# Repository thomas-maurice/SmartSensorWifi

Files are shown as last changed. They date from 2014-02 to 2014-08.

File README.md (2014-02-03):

# Smart Sensor WiFi
## General information

 * Developpement status : *work in progress*
 * Project version   : 0.1 alpha

Project led by:

 * Thomas Maurice <Thomas.Maurice@polytech-lille.net>
 * Benoit Maliar  <Benoit.Maliar@polytech-lille.net>

## About the project
This project aims to build a network of sensors which can easily be
deployed into any building to monitor it. The sensors would be able to
monitor temperature, light, moist, presence and so on and send everything
to a centralized database into which data will be stored and processed.

We can easily imagine which use can be done of this kind of sensor networks
in the field of energy-efficient building.

For now, this project is part of a student project led by Polytech'Lille,
a french school of engineering.

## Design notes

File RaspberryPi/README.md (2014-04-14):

RaspberrySPI
============

A base class to implement full duplex SPI communication, simple to extand to create custom SPI drivers

A nice Doxygen powered doc can be found [here](http://doc.svartbergtroll.fr/raspberryspi).

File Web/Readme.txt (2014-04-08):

Manuel d'utilisation de la plateforme Web Smart Sensor Wifi

Index : Connexion
Ajout d'un capteur
Suppression d'un capteur
Recherche d'un capteur
Administration

------------------WARNING------------------------

Don't forget to configure the 'connexion.php' file with your configuration before using.

-----------------WARNING-------------------------

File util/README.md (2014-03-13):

# util

These files are provided as 'helpers' to use/dev/debug the project.
They are not quite documented/re-usable because their sole purpose
is being used in the Smart Sensor WiFi project's developement.
Of course everything here is under the GPL License.

## pyserialcom.py
This script provides a simple user-friendly and swaggy alternative to
*minicom*. It enables you to communicate with the mictocontroller via
the serial port. The advantage is that if a character is not printable,
it won't result in a horrible and unprintable result. You can choose
between an ASCII output, a hex output and a mixed output.

To launch it just type :

    ./pyserialcom.py [serialport] [baudrate=9600]

and enjoy ;)

## postJson.sh
This script is used to emulate the data send by a sensor to check
if the insersions into the database are effective or not.

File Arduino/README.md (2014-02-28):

# Smart Sensor WiFi - microcontroller Part
## General information

 * Developpement status : *work in progress*
 * Project version   : 0.1 alpha
 * Developper : Thomas Maurice <Thomas.Maurice@polytech-lille.net>

# Introduction
 
This project is a student project managed by Polytech Lille Engineering
School. It is led by two students, *Thomas Maurice* and *Benoit Maliar*. Both
students in 4th year.

The aim of the project is to create a distributed WiFi sensor network
that is able to regularly communicate various data to a central DB and
autoreconfigure itself in order to be energy efficient.

Note that the project is open source and you can modify it. Especially
the drivers for the RTC and the WiFi chip, you are more than welcome to
study and improve them.

# Hardware

The project uses the following hardware :

* An atmega328p (An Arduino Uno board for the developpement).
* A DS1302 real time clock for time-keeping.
* A photoresistor and temperature sensor.
* A WizFi210 WiFi chip.

# Getting the code's doc

This is easy. The documentation for the source code is located in the
code itself with **Doxygen** comments. This means that you have to install *doxygen*
on your computer and run `doxygen Doxyfile` in the Arduino folder. This will
generate a pretty HTML documentation in the `doxygen/html` folder. Feel free
to navigate it.

# Compiling

To compile the project you just need AVR-gcc installed. Just go in the
`Arduino` directory and run `make`. Everything will compile well. If
not, just undo your changes to my code !

It will create a nice .hex for upload. If your target is an Arduino board
then just type `make flash` to upload it using the built-in bootloader.
If it is just a bare-metal atmega328p then wire it up to your USBASP
device and run avrdude with the good options.

Have fun :)

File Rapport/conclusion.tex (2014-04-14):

\addcontentsline{toc}{section}{Conclusion}
	\section*{Conclusion}
		\par
		En conclusion, nous avons répondu à la problématique qui nous a été posée en fournissant un prototype de capteur qui envoie des données via le réseau Wifi. De plus, une plate-forme permettant de monitorer ces capteurs a été conçu.
		\par
		Un des points auquel nous n'avons pas totalement répondu est la sécurité du réseau. A la base, nous devions fournir un capteur capable d'envoyer ses données via le réseau de l'université (PEAP) mais cela n'a pas été possible avec le firmware fourni de base mais qui est possible en obtenant le firmware auprès du concepteur du shield Wifi. Néanmoins, le prototype final est tout de même capable de fonctionner sous WPA2.
		\par
		La façon dont nous avons réalisé le projet permet de continuer et d'améliorer assez aisément le projet en vu d'une évolution ou d'une mise en production.

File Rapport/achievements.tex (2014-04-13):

% !TEX encoding = UTF-8 Unicode
\section{Cahier des charges}
	\par
	Le cahier des charges a été formulé comme il suit : L'objectif du
	projet consiste en la conception et la réalisation de capteurs autonomes
	communiquant en WiFi afin de pouvoir remonter réguliérement des informations
	sur l'état des salles de cours. Les capteurs seront par exemple des détecteurs de
	lumières, de pression, de qualité de l'air, ...
	\par
	La communication sera obligatoirement réalisée en WiFi sur le réseau
	de l'université en respectant les contraintes de sécurité (WPA2, ...).
	\par
	Deux options sont possibles :
	\begin{itemize}
    \item Refaire complètement une carte avec un microcontroleur et une
    puce wifi (comme par exemple les \href{https://www.spark.io/}{spark})
    \item Réaliser un shield pour raspberry pi contenant les différents capteurs. 
	\end{itemize}
	
\section{Présentation de la réalisation}
	\subsection{Présentation de la partie web}
		\par
		La partie Web du projet offre une interface de supervision et de monitoring des capteurs. En effet, nous avons pense qu'il ne suffisait pas de réussir à envoyer des données en Wifi par le biais des capteurs, il fallait aussi pouvoir récupérer et stocker ces informations en vue d'un potentiel traitement. 
		\par
		On a donc décidé de récupérer ces informations dans une base de données qui serait gérée par une plateforme Web.
		\subsubsection{La base de données}
		\par
		La base de données que nous avons utilisée est celle offerte par Polytech'Lille, comme à chaque étudiant de l'école. Nous avons donc opté pour une base MySQL avec le panneau d'administration PHPMyAdmin. Le choix de MySQL est simplement justifié par une meilleure connaissance et habitude des requêtes et commandes SQL, contrairement à PosgreSQL (bien qu'il y ait peu de différences).
		\subsubsection{La plateforme Web}
		\par
		L'accès à la plateforme se fait via l'url suivante : \href{http://smartsensorwifi.plil.net}{Smart Sensor Wifi.}
		\\%
		Le site n'est pas en mode sécurisé (https) pour une raison simple : le shield Wifi ne supporte pas l'https dans le firmware actuel (celui livré de base). C'est donc pour cela que nous avons choisi de le mettre en http simple (bien qu'il puisse être basculé en https très rapidement et simplement sans poser aucun souci de compatibilité).
		\par
		Au niveau langage de programmation, le site est en HTML et PHP. Nous avons choisi le PHP, plutôt que le Python ou autre, car le PHP était plus familier et offrait toutes les opérations nécessaires. De plus, une petite partie du site utilise du Javascript afin de rendre plus dynamique et interactif le site.
		\par
		Au niveau design, nous avons décidé d'utiliser deux frameworks libres : Ink et Chart.js. Le premier gère le design global du site et le second est utile à la création de graphiques. Nous avons décidé d'utiliser des framework afin de rendre le site plus propre et d'offrir à l'utilisateur un outil visuellement agréable à utiliser.
		\par
		Au niveau technique, la plateforme est un simple intermédiaire entre, d'une part les capteurs et la base de données, et d'autre part, les utilisateurs et la base de données. D'un côté, le site récupère les informations que les capteurs lui envoie et stocke ces données dans la base. De l'autre côté,  à travers différents boutons et champs, l'utilisateur peut récupérer les informations qu'il désire.
		
	\subsection{Présentation de la partie capteur}
		\subsubsection{Le hardware}
		\par
		A la fin du projet, nous avons réalisé un prototype fonctionnel de ce
		que pourrait être le capteur. Il est important de noter que nous n'avons
		pas cherché à intégrer la solution mais plutôt à la développer en terme
		de fonctionnalités. De ce fait le prototype est assez volumineux mais
		sa taille peut aisément être réduite en utilisant des solutions à base
		de composants CMS notamment ce qui permettrait de réduire de manière
		significative l'encombrement de l'appareil.
		\par
		Le prototype final se compose donc de trois éléments principaux. Le coeur
		du système est réalisé avec un Arduino Uno. Une platine de développement
		sur microcontroleur basée sur un ATmega328P de chez Atmel. C'est dans cet
		Arduino qu'est flashé le programme du capteur. Vient en suite la partie
		qui prend en charge le WiFi, il s'agit d'un shield WiFi de chez GoTronic
		basé sur la puce WizFi210 de WizNet, cette dernière est interfacée avec
		l'Arduino via le port série. Enfin la dernière partie est un protoshield
		sur lequel est placé une breadboard sur laquelle sont enfichés les composants
		avec lesquels l'Arduino peut interagir, à savoir :
		\begin{itemize}
			\item Une photorésistante pour capter la luminosité
			\item Un capteur TMP36 de température
			\item Une RTC (Real Time Clock) DS1302
		\end{itemize}
		Notons que nous avons choisi ces capteurs pour leur facilité d'utilisation,
		mais dans l'absolu rien n'empêche d'utiliser n'importe quel autre capteur
		analogique ou TOR, ni même d'interfacer le système avec des choses plus
		complexes à base de SPI ou d'I$^2$C, étant donné que l'ATmega328P en a
		la possibilité.
		\par
		Le principe de fonctionnement du capteur est très simple. Une fois configuré
		à l'aide de \texttt{configurator} (dont le fonctionnement sera détaillé ci après)
		il vous suffit de déployer le capteur là où vous souhaitez qu'il opère et le
		laisser envoyer des mesures à intervalles d'une minute. On dispose ainsi
		d'un suivi efficace de l'environnement. Aussitôt que l'appareil est
		mis sous tension il va essayer de se connecter au réseau qui lui a été
		spécifié en configuration et une fois que cela s'est fait correctement il
		va passer en mode interruptif et enverra ses mises à jour toutes les minutes.
		Il faut aussi noter que pendant ce temps là, le capteur écoutera les connexions
		entrantes sur le port 80 et pourra ainsi être reconfiguré par ce biais à l'aide
		d'un set de commandes AT décris et documenté en annexe.
		
		\subsubsection{Le software}
		La partie logicielle du projet est découpée en deux parties. La première
		consiste en le firmware que nous avons chargé dans l'Arduino, et qui est chargé
		de gérer la carte WiFi et les différents capteurs.
		\par
		La seconde partie consiste en un logiciel de configuration écrit spécialement
		pour ce projet, il s'agit de \texttt{configurator}. C'est un script en python
		qui permet via une interface graphique plutôt intuitive de configurer un capteur,
		et ce que ça soit par le port série d'un capteur directement relié au PC en USB
		ou via le réseau en utilisant une socket TCP.

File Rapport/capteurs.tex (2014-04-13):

\section{Détail de la conception de la partie microcontrôleur du projet}
	\subsection{Le capteur}
		Lors de la réalisation du senseur il a fallu en premier lieu se fixer
		des objectifs à atteindre, afin d'être sûr d'aller dans une direction
		cohérente tout au long du projet. De  ce fait nous avons choisi d'opter pour
		la réalisation d'un prototype fonctionnel et relativement simple au début.
		Par relativement simple, nous entendions capable de lire un ou deux capteurs
		analogiques simples à mettre en place de manière à nous focaliser sur
		l'interfaçage du dispositif avec un serveur de données. Nous nous sommes
		donc d'avantage focalisés sur une approche plus logicielle du projet en
		écartant volontairement, par manque de temps, des considérations annexes
		comme la gestion de l'énergie ou la mise en place immédiate de capteurs
		très complexes. Le but était réellement de fournir une base saine sur laquelle
		il serait facile de s'appuyer à l'avenir.
		
		\subsubsection{La partie électronique}
		
		La partie électronique est la plus simple de l'appareil c'est donc celle
		là qui sera abordée en premier. Elle se compose simplement d'une photo résistance
		montée en pull up sur la patte analogique 1 de l'Arduino et d'un capteur de
		température câblé sur la patte analogique 2. Nous avons également câblé un bouton de
		mise à jour (dont l'utilité sera détaillée plus tard) sur la patte PD2
		ainsi que la real time clock sur trois pattes numériques de manière à pouvoir
		échanger des données. Tout ces composants ont été positionnés sur une breadboard
		de manière à ce que nous puissions facilement en modifier l'arrangement au fur et a mesure
		que nos besoins évoluaient dans le projet.
		\par
		Nous n'avons malheureusement pas eu le temps de réaliser de carte
		pour fixer ce design. Et il n'aurait pas été pertinent de le faire dans la mesure
		ou la conception, le routage et la fabrication d'une carte sont des activités pour
		le moins chronophages et qu'il a effectivement été plus productif pour nous de nous
		concentrer sur l'ajout de nouvelles fonctionalités au capteur. Cependant
		nous avons édités des PCB et des schémas électroniques disponibles en
		annexe qui permettent de réaliser une telle carte.
		
		\subsubsection{Conception du firmware de l'Arduino}
		La conception du firmware de l'arduino s'est découpée en plusieurs étapes.
		Pour commencer nous avons séparé les différentes fonctionnalités que nous
		souhaitions. D'un point de vue organisation cela s'est traduit par un fractionnement
		du code en plusieurs fichiers, chacun regroupant les fonctions relatives à un
		domaine, par exemple la gestion du port série, des CAN, de l'EEPROM et autre.
		\par
		Ensuite, une fois que la séparation logique des fonctionalités a été effectuée
		nous avons commencé à les développer une à une, en lançant à chaque fois une
		série de tests sur ce que nous avions créé, de manière à nous assurer que tout
		était bien conforme à ce que nous attendions. De cette manière nous pouvions
		réutiliser sans crainte le code que nous avions précédemment écrit puisqu'il
		avait été validé par une batterie de tests.
		\par
		Une attention toute particulière a été portée à la documentation. En effet si nous
		souhaitons que le projet puisse être repris les années suivantes il
		est indispensable de fournir une documentation valable, fiable et complète
		de manière à ce que n'importe qui ou presque soit en mesure de comprendre
		ce qui a déjà été réalisé de manière logicielle. Pour ce faire nous avont eu
		recours au système de documentation in-code Doxygen, qui grâce à un
		système de commentaires au formattage particulier permet de générer automatiquement
		une belle documentation HTML. Cette documentation navigable est facile à utiliser, avec outils
		de recherche intégré et liens entre les différentes fonctions documentées.
		Si vous souhaitez construire la documentation du programme rendez vous dans
		le répertoire Arduino et tapez simplement \texttt{doxygen} un dossier contenant
		le nécessaire sera généré pour vous !
		\par
		La seconde partie du projet, qui n'est au final même pas utilisée dans le prototype
		actuel, a été la réalisation d'un driver pour la real time clock de Maxim DS1302.
		Ce driver a été implémenté en utilisant le protocole de communication 3-Wire décrit dans
		la datasheet, c'est un protocole similaire au protocole SPI mais suffisamment différent de celui ci
		pour ne pas pouvoir utiliser le contrôleur SPI de l'Arduino. Le driver est fonctionnel et
		permet d'accéder aux registres de temps de la RTC ainsi qu'aux quelques octets de RAM qu'elle
		nous fourni en plus, ce qui peut être pratique si jamais l'arduino venait à en manquer. Toutes
		les informations nécessaires sont bien évidemment documentées dans le code et via Doxygen.
		\par
		Nous somme partis du constat que le fonctionnement du WiFi pouvait être parfois
		assez instable, et que de ce fait il serait appréciable que le capteur puisse se comporter
		comme une sorte de datalogger dans le cas où il serait dans l'incapacité momentanée de communiquer
		avec le serveur de donnée, que cela soit a cause du wifi ou d'un autre problème d'ailleurs.
		Pour cela nous avions pensé le coupler avec une flash (voir les schémas en annexe). Cela dit
		comme le composant n'était disponible qu'en format SOIC8 et que nous n'avons pas réalisé la carte
		il nous a été impossible de l'intégrer correctement. Une amélioration possible et très facile à
		mettre en oeuvre pour le projet serait donc l'intégration de cette flash et l'utilisation
		de la RTC pour soumettre en différé des données de mesures qui n'auraient pas pu être
		transmises à temps.
		\par
		La troisième partie du projet a été consacrée à faire en sorte que la configuration du capteur
		soit persistante entre les reboots. Durant les phases de développement nous ne nous étions pas
		vraiment occupés de cela mais dès que le programme est devenu plus compliqué il est devenu
		essentiel de stocker certains paramètres (d'identifications notamment) autrement qu'en dur
		dans le code. Il a donc fallu ajouter un module de gestion de l'EEPROM. La structure suivante a donc
		été choisie pour stocker des données :
		\begin{itemize}
			\item L'EEPROM est découpée en différents secteur de taille fixé à la compilation
			\item Chaque secteur contient un octet de taille et $N$ octets de données ($N < 255$)
			\item Chaque secteur est uniquement défini par sa position en mémoire
		\end{itemize}
		
		Cette solution présente l'avantage d'être très simple à mettre en place d'un point de vue
		logiciel, ce système souffre cependant d'un gros problème qui est que l'on ne peut
		pas connaître de manière dynamique la taille maximale des données que l'on peut ranger
		dans un segment. Ce qui implique que le programmeur fasse très attention aux données qu'il
		manipule, de manière à ne pas provoquer de débordement sur un autre segment. Ceci dit,
		ce problème n'est pas vraiment critique puisqu'une simple réécriture de la configuration
		rétablira tout correctement. Ceci fait également partie des améliorations possibles
		du projet.
		
		\par
		La quatrième partie du projet a sans aucun doute été la plus difficile à réaliser. En
		effet après s'être occupé des briques élémentaire qui compose le capteur (communiquer
		en série, lire des capteurs analogiques, lire la RTC). Il a fallu regrouper tout ça
		ensemble et l'envoyer sur internet. Pour se faire, il a d'abord fallu comprendre comment
		fonctionnait la carte WiFi. La datasheet n'étant pas toujours très claire, ni très complète
		il a d'abord fallu passer par une phase \og{} d'exploration \fg{} de la carte via le port
		série, de manière à comprendre précisément ce qu'elle attendait de nous en terme de commandes.
		La carte se configurait finalement par un set de commandes AT via le port série et malgré
		les quelques imprécisions de la datasheet nous avons finalement été capables de nous identifier
		sur un réseau spécialement créé pour l'occasion.
		
		\par
		A partir de là a été développé une petite bibliothèque qui intègre les fonctions réseau de base,
		à savoir s'identifier sur un réseau avec des paramètres donnés, soumettre des requêtes HTTP et
		vérifier le retour des commandes AT de manière à réitérer plusieurs fois une tentative de connexion
		qui aurait échoué. Cette bibliothèque fonctionne sur le port série via une scrutation, elle n'utilise
		pas d'interruptions pour avoir plus de contrôle et intercepter tout ce qui circule sur le port série
		et le conserver au sein du même contexte (il est préférable que le retour d'une commande reste interceptée
		par la fonction qui l'a émise plutôt que de devoir passer par une interruption globale et deviner
		quelle fonction a besoin des données reçues).
		
		\subsubsection{Communication avec l'application web}
		Une fois la carte configurée et connectée au réseau, il a fallu envoyer des données de mise à jour au
		site de Benoit. Nous avions au départ pensé à faire ça via post en JSON, simplement ça aurait
		été trop long et gourmand à mettre en place niveau mémoire (les données post doivent avoir
		une longueur définie et il faut encoder les caractères "{:," qui sont très utilisées dans une
		chaine JSON ce qui aurait rendu l'envoi des données affreuse). Du coup nous avons opté pour un
		format d'envoi en post classique. Voici par exemple la requête POST que le capteur "cap1" doté du mot de passe
		"coucoutuveuxvoirmadata" aurait envoyé :
		
		\begin{verbatim}
    POST /recup.php HTTP/1.0
    Host: smartsensorwifi.plil.net
    Content-type: application/x-www-form-urlencoded
    Content-length: 100
    
    temp=140&lum=17&mid=cap1&mpass=coucoutuveuxvoirmadata
		\end{verbatim}
		
		\par Notons que les valeurs envoyées peuvent paraître étranges, mais elle ne sont que la lecture
		directe du CAN de l'ATmega, la serveur les traitera pour les transformer en température ou
		déterminer le seuil de luminosité. Ainsi on décharge le microcontrôleur d'une partie
		du travail.
		
		\subsubsection{Reconfiguration du capteur}
		Une fois que le projet est capable de communiquer avec l'appli web, de soumettre
		des données, de se connecter à un réseau et ce genre de chose il ne lui manque pas beaucoup de fonctionnalités.
		Ceci dit une fonctionnalité indispensable s'est vite faite ressentir :
		le besoin de pouvoir reconfigurer le capteur à distance. En effet, le
		seul moyen de reconfigurer le capteur était en modifiant en dur dans le code les identifiants et
		de reflasher le programme ensuite, ce qui n'est pas pratique.

		Pour palier à ce problème nous avons donc créé un set relativement complet de commandes AT,
		documentées en annexe. L'idée est que le capteur écoute ce qu'il se passe sur son port série
		et dès qu'une commande AT est reconnue elle est exécutée pour peu que l'on soit authentifié sur
		le capteur. Pour se faire nous avons établi deux modes de configuration, une configuration "locale" via
		le port série, et une reconfiguration à distance via le réseau. 
		
		\subsubsection{Principales difficultés rencontrées}
		
	\subsection{Configurator.py}
	\begin{wrapfigure}{r}{40mm}
		  \centering
		  
		  \caption{Interface de configurator}
		  \vspace{-20mm}
	\end{wrapfigure}
		Afin que l'utilisateur n'ai pas a se munir de minicom ou de netcat pour reconfigurer
		ses capteurs, nous avons choisi de développer un logiciel dont le rôle est de se
		charger de la configuration à la place de l'utilisateur. Qu'il s'agisse d'une configuration
		locale via le port série ou à distance via le réseau, configurator fait le lien
		entre l'utilisateur et son capteur. Le logiciel dispose d'une interface très simple composée
		de quelques champs et de deux boutons, un pour rapatrier la configuration d'un capteur et l'autre
		pour envoyer une configuration à un capteur. De cette manière il n'est plus utile de connaître
		par coeur les commandes AT nécessaires à la configuration de l'appareil. Ce logiciel a été
		réalisé en python avec pygtk, glade2 et pyserial.
	
	\subsection{Tentative de substitution par une solution a base de RaspberryPi}
		Comme la carte WizFi tardait à arriver, nous avons pensé opter pour une solution alternative
		pour réaliser le capteur, à base d'une RaspberryPi. Certes la solution était un peu surdimensionnée
		pour ce que l'on voulait en faire, mais comme cela on aurait eu quelque chose de fonctionnel
		à montrer lors de la soutenance. L'idée était d'utiliser les GPIO de la Raspberry pour
		l'interfacer avec le monde exterieur.
		\par
		Malheureusement la RaspberryPi est un appareil qui ne dispose pas d'entrées analogiques,
		ce qui est assez peu pratique pour lire une température ou une luminosité de la même manière que
		sur un ATmega. Nous avons donc dû recourir à un ADC externe fonctionnant suivant le protocole SPI,
		ce qui tombait plutôt bien puisque la Raspberry est équipée d'une inetrface SPI lui permettant
		de contrôler jusqu'à deux esclaves. Pour notre problème nous avons opté pour l'ADC MCP3208 de
		MicroChip. Pourquoi celui là ? Tout simplement parce qu'il dispose de huit canaux analogiques ce qui
		permet une grande variété de capteurs, mais également parce qu'il peut fonctionner en 3v3, tension à
		laquelle fonctionne également la Raspberry, ainsi on évite de la griller.
		\par
		J'ai donc réalisé une carte et un PCB pour réaliser cette alternative, mais également
		la couche logicielle qui va avec. J'ai en effet développé une classe en C++ qui
		encapsule tout les appels systèmes permettant d'écrire et de lire sur le port SPI
		de la raspberry, en full duplex. J'ai en réalité réalisé deux classes, une classe
		SPI qui est la classe mère, comprenant seulement les routines d'initialisation et d'écriture
		du port SPI, et une SPI\_MCP3208 qui comprend les commandes spécifiées dans la datasheet
		du composant.
		\par
		Pour information, cette classe et le programme d'exemples sont disponibles sur GitHub et la
		documentation est disponible à l'addresse spécifiée dans le wiki du projet.
		\par
		Cela dit, il y a eu un problème, il était que les données renvoyées par l'ADC étaient
		totalement incohérentes. Le fait est qu'à luminosité égale, si on lançait 10 acquisitions
		nous pouvions obtenir des écarts de plus de 3000 (sur 4095 d'amplitude) entre
		deux valeurs, quand bien même la luminosité ne variait pas. Le plus déroutant
		dans tout cela c'est que le problème n'avait pas l'air de venir de notre logiciel,
		dans la mesure ou nous étions parfaitement capables, avec la même couche logicielle,
		de piloter d'autre appareils SPI fonctionnant en esclave (comme un afficheur 4x7
		segments de chez SparkFun par exemple). La seconde chose la plus dérourante était
		que les données étaient cohérentes du point de vue du fonctionnement du composant
		tel que décrit dans la datasheet. Je m'explique, une trame classique de communication avec
		l'ADC se compose comme il suit (schématiquement) :
		\\
		\texttt{4 bits de commande | deux bits de sample | 12 bits de résultat MSB first}\\

		Le fait est que d'après la datasheet en continuant à envoyer des coups d'horloge
		au composant après le dernier bit de donnée, le composant va nous renvoyer le
		résultat de la conversion mais LSB first. On récupère donc le symétrique des données
		par rapport au LSB. Après avoir analysé plusieurs séquences nous avons pu constater que
		l'erreur ne venait pas de la manière dont nous récupérions nos données puisqu'elles étaient
		correctes du point de vue de la datasheet mais totalement aberrantes d'un point de vue physique.
		\par
		L'erreur ne venait pas non plus du hardware puisqu'un rapide coup d'oeil à l'oscilloscope nous a
		permis de constater que la tension sur la patte de l'ADC évoluait bien comme elle le devait.
		Le mystère est resté entier puisqu'après nous avons reçu la carte WizFi et nous avons pu commencer
		à travailler dessus, cette solution a donc été abandonnée. Cela dit, nous avions déjà commencé à
		réfléchir aux technologies que nous aurions pu mettre en place pour réaliser la solution, qui auraient été :
		\begin{itemize}
			\item Un programme de lecture des données appelé par cron à intervalle régulier (un bête script bash
			qui lit le port SPI et conditionne les données en POST par exemple pour les envoyer au site de Benoît)
			\item Une application Web similaire à celle de Benoît mais ne concernant que les données locales
			de l'appareil, qui aurait permis de modifier les paramètres de mises à jour/sécurité tout
			simplement depuis un navigateur. Nous avions pensés à la réaliser en Python avec CherryPy un
			excellent framework python très léger, et évidemment Ink pour le design. 
		\end{itemize}

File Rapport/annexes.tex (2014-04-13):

~~
\vspace{10cm}

\begin{center}
\Huge{Annexes}
\end{center}
\newpage

\includepdf[pages={1-}]{AnnexesWeb.pdf}
\includepdf[pages={1-}]{SensorATCommands.pdf}
\includepdf[pages={1-}]{useConfigurator.pdf}
\includepdf[pages={1-}]{SmartSensorWifiUART.pdf}
\includepdf[pages={1-}]{RaspberryShield.pdf}

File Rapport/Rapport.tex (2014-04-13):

\documentclass[12pt,a4paper]{article}

% Packages standards

\usepackage[utf8]{inputenc}
\usepackage[T1]{fontenc}
\usepackage[francais]{babel}
\usepackage{lmodern}

% Configuration
\def\NomAuteur{Maurice}
\def\PrenomAuteur{Thomas}
\def\Titre{Rapport de projet de quatrième année\\Smart Sensor WiFi}
\def\TitreCourt{Rapport de projet Smart Sensor WiFi}

% Infos du document
% Auteur et tout ça
% Mise en page

\usepackage{hyperref}
\usepackage{fancyhdr}
\usepackage{geometry}
\usepackage{titlesec}
\usepackage{listings}

% Pour include PDF :
% \includepdf[pages=n-m]{fichier.pdf}
\usepackage[final]{pdfpages}

% Urls & figures

\usepackage{url}
\usepackage{graphicx}
\usepackage{wrapfig}

% Configuration de l'article

\hypersetup{
	pdftitle={\Titre}, 	% Titre
	pdfauthor={\PrenomAuteur \NomAuteur}, 	% Auteur
	colorlinks=true,			% Couleur des liens
	linkcolor=black,			% Couleur des liens
	urlcolor=black				% Couleur des liens
}

% Géométrie

\geometry{
	a4paper,
	body={150mm,250mm},
	left=20mm,
	right=20mm,
	top=20mm,
	bottom=20mm,
	headheight=7mm,
	headsep=4mm
}

\pagestyle{empty}

 % Titre du document

\newcommand{\titre}[1]{
						\textbf{
							\LARGE{
								\begin{center}
									#1
								\end{center}
							}
						}
					}

% En-tête du document

\newcommand{\makehead}{
	~~
	\vspace{3cm}
	\titre{\Titre}
	\vspace{3cm}
	\begin{center}
		\PrenomAuteur~\bsc{\NomAuteur} \\
		Benoit \bsc{Maliar} \\~\\
		École Polytechnique Universitaire de Lille \\
		Département IMA \\
		~\\
		\href{mailto:thomas.maurice@polytech-lille.net}{\texttt{Thomas.Maurice@polytech-lille.net}} \\
		\href{mailto:benoit.maliar@polytech-lille.net}{\texttt{Benoit.Maliar@polytech-lille.net}} \\
		~\\
		\today\\
	\end{center}
	\vspace{5cm}
	\begin{center}
		\begin{tabular}{l r}
			 ~~~~~~~~~ & ~~~~~~~~~  \\
		\end{tabular}
	\end{center}
	
	\newpage
	\renewcommand{\headrulewidth}{0.4pt}
	\renewcommand{\footrulewidth}{0.4pt}
	
	\pagestyle{fancy}
	\fancyhead[L]{\bsc{Maliar - Maurice} IMA4}
	\fancyhead[R]{\TitreCourt}
	\fancyhead[C]{}
	\fancyfoot[C]{}
	
	\tableofcontents
	\newpage
	\pagestyle{fancy}
	\fancyhead[L]{\bsc{Maliar - Maurice} IMA4}
	\fancyhead[R]{\TitreCourt}
	\fancyhead[C]{}
	\fancyfoot[C]{\thepage}
	\setcounter{page}{1}
}

\begin{document}
	\makehead
		
		\setlength{\parskip}{12pt}
		\include{intro}
		\include{achievements}
		\include{web}
		\include{capteurs}
		\include{conclusion}
		\include{annexes}
		
\end{document}

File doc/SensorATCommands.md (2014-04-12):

# Communicate with the SmartSensors via AT-commands

## Introduction
If you are familiar with the use of microcontroller devices such as
XBee chips or so you migh know what the AT commands ar for : they
enables you to configure your device via a textual mode. You are very
lucky since the SmartSensors are shipped with a set of a dozen AT commands
which enable you to configure it quite easily.

The main advantage of these AT commands is that they are accessible
both in serial mode *as well as* in WiFi mode. That is to say that
you can reconfigure your sensors remotely via the wifi, provided the sensor
has already access to a network. Cool isn't it ?

To do so, the `util/` folder contains the **configurator.py** software
wich can connect and update/download a sensor configuration. Just run it
the fields/buttons are quite self explanatory.

## Identification
To identify on the sensor, you have to know something called the **master key**
of the sensor. This is a code that you must enter before trying to do anything
on the sensor. The command for that is `AT+IDENT=masterkey`.

## The commands

The generic syntax for an AT command is the following : `AT+COMMAND=ARG`. If you
are coding something about it, don't forget to add an `\n` or an `\r` after
the command.

### Sensor configuration
These commands are used to configure the sensor itself and it's identification
onto your database server.

 * `AT+ID` : Changes the ID of the sensor to access the website
 * `AT+PW` : Changes it's password
 * `AT+IPDB` : Changes the IP of the data server
 * `AT+HOSTDB` : Changes the hostname of the data server

### Network configuration
 
 * `AT+DHCP` : 1 if DHCP is used, 0 if not. If DHCP is used you don't need further config.
 * `AT+NIP` : IP address of the sensor
 * `AT+NGW` : Gateway IP
 * `AT+NMSK` : Netmask

### Wireless configuration

 * `AT+ESSID` : Obviously sets the ESSID of the network. Does not matter if visible or not
 * `AT+WKEY` : Sets the passphrase for the sensor
 * `AT+NETTYPE` : Sets the type of network according to the following values :
    * 0 : Auto
    * 1 : Open authentication
    * 2 : WEP authentication
    * 4 : WPA PSK
    * 8 : WPA2 PSK

### Security

 * `AT+MASTER` : Changes the Master key.
 * `AT+IDENT` : Identify on the sensor. The parameter is the master key.
 
### End of sequence

 * `AT+EXIT` : This command shall be issued at the end of every command sequence end.

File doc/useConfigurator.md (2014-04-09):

# Configurator
*one software to conf them all*

## Introduction
If you succeeded to build a sensor and to upload a firmware onto it (GG)
you are probably wondering "How the hell am I supposed to confiigure it
in order to make it work with my network and with my server" aka "WTF?".

Well **configurator.py** is the answer ! This software is designed to allow
you to configure a sensor device either from your computer through the network
or through a serial link to perform the initial configuration.

## How do I launch it ?
That's rather easy. You just fave to go into the util/configurator folder
then run `python configurator.py`. Note that you have some dependencies to
satisfy in order to run the software, namely :

 * python (you don't say)
 * python-serial
 * python-gtk, python-gtk2 or pygtk depending on how the package is called in your distro

## How do I use it ?
Well, the interface is quite simple actually. And the field are quite self
explanatories. All you need to do is to fill in all the forms and hit the
"Connect and upload" button. If some important fields are not properly filled
then an error shall be raised and nothing will be uploaded. You will not break your config :)

If you just want to edit it, you can alternatively load the config from a sensor
to your interface. Then identically just hit the "Connect and download" button.

## Let's do that !
Yep, but before you get frustrated because "stupid software won't work" you
have to know that an initial serial configuration requires a slight physical
interraction with the device. That is to say you have to do two things :
firstly you have to change the switch of the wifi shield from the "Run" to
the "Prog" mode. Then while pressing the "Download" or "Upload" button you
have to press the pushbutton located on the right part of the shield. This will
allow the device to be serially configured.

To do this wirelessly you don't need such manipulations. Just fill in the address
and here you go !

## Master key
Note that you don't need to provide the master key if you are reprograming
the software via the serial link.

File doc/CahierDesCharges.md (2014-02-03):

# Projet 42 : Smart Sensor Wifi
*Binôme Thomas Maurice - Benoit Maliar, IMA4SC*

## Énoncé initial du projet
L'objectif du projet consiste en la conception et la réalisation de
capteurs autonomes communiquant en WiFi afin de pouvoir remonter
régulièrement des informations sur l'état des salles de cours.
Les capteurs seront par exemple des détecteurs de lumières,
de pression, de qualité de l'air, ...

La communication sera obligatoirement réalisée en WiFi sur le réseau
de l'université en respectant les contraintes de sécurité (WPA2, ...).

Deux options sont possibles :

 * Refaire complètement une carte avec un microcontroleur et une puce wifi
 (comme par exemple les [spark](https://www.spark.io/))
 * Réaliser un shield pour raspberry pi contenant les différents capteurs. 

## Analyse rapide du sujet
On a ici affaire à un réseau de capteurs reliés à une base de donnée centrale
qui est chargée d'interroger régulièrement les différents capteurs de manière
à pouvoir présenter à un utilisateur un état des différentes pièces dans
lesquelles on aura disposé les capteurs. Cela peut notemment impliquer :

 * Un accès à ces données via une interface web
 * Un accès à ces données via une application mobile
 * Un accès à ces données via un programme desktop
 
On identifie donc deux parties au projet :

 * La partie capteur
 * La partie serveur

Et on déduis donc l'architecture de la Figure 1.

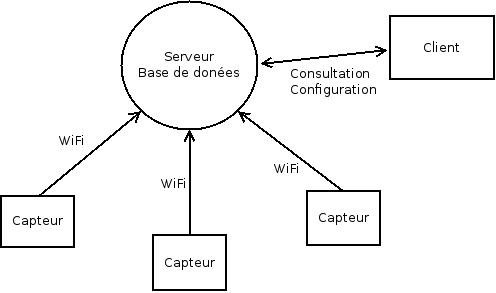
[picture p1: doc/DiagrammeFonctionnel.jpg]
Diagramme fonctionnel


## Cahier des charges
### Spécifications des capteurs
Les caractéristiques souhaitées pour les capteurs sont :

 * Être capable de mesurer l'environnement dans lequel évolue le capteur
   (Pression, température, lumière, présence, ouverture de porte...)
 * Contacter le seuveur via le WiFi pour actualiser la base.
 * Éventuellement, être reconfigurable à distance.
 * Éventuellement être capable de gérer sa consomation d'énergie.
 * Agir en temps que datalogger si le réseau n'est pas accessible.

### Spécifications du serveur
Les caractéristiques souhaitées pour le serveur sont :

 * Être capable de contacter ou d'être contacté par les capteurs via le réseau.
 * Respecter les contraintes de sécurité (WPA2)
 * Être capable d'authentifier les clients
 * Stocker les données reçues dans une base de données et éventuellement
   faire des calculs et des statistiques sur ces données.
 * Présenter sous format compréhensibles les données au client (web ou appli)
 * Vérifier l'état des capteurs et notifier un responsable en cas d'anomalie
   (déconnexion du réseau, valeur anormale d'un capteur...)

## Propositions de solutions technologiques
### Les capteurs
Nous proposons de réaliser une carte basée sur un ATmega328 dans lequel
on pourra flasher du code Arduino. Pour gérer le WiFi, nous proposons
une solution utilisant le board CC3000 d'Adafruit 
[lien ici](http://www.adafruit.com/products/1469).
L'avantage de cette solution est que la carte est optimisée pour les
breadboards et peut du coup facilement être clipsée sur la carte.
Elle possède également l'avantage d'être fournie avec la bibliothèque
Arduino qui va bien (et qui est bien open source) de manière à
pouvoir être pilotée depuis un Arduino ou dans notre cas un AVR tout
simple. Enfin, le dernier avantage est qu'Adafruit travaille en mode
*Open Hardware* ce qui signifie que les plans de la carte sont
disponibles en ligne, ce qui nous permettrait d'intégrer la carte WiFi au
sein de notre projet facilement dans un second temps.

Dans un premier temps, on se concentrera sur la mise en place
d'un prototype fonctionnel a base d'un simple capteur de température. On
étendra ensuite les capacités de la chose à des capteurs peut être
plus complexes style I2C ou SPI.

### Le serveur
On propose une solution à base d'une machine sous Linux (Raspberry Pi
pour une version plus compacte
ou un vrai serveur pour une version destinée à administrer des
réseaux de capteurs de taille plus importante.

Le SGBD utilisé serait **MySQL** ou **SQLite**.

La partie web du serveur destinée à présenter à l'utilisateur une vue
des données serait développée en PHP/HTML5/CSS3.
La partie serveur qui recevra les flots de communication des capteurs
serait programmée en Python. Cette partie servira
à recueillir les données des capteurs et à les formater pour les insérer
dans la base. Éventuellement des opérations
pourront être effectuées sur ces données, exemple transformer un entier
8 bits en une température entre 20° et 30°.

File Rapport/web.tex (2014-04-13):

\section{Détail de la partie web du projet}
\par
Cette partie aura pour but de présenter la partie Web du projet sous un oeil technique. On présentera donc en détail les méthodes utilisées ainsi que les choix techniques qui composent notre projet.
	\subsection{La base de données}
	\par
	La base de données, qui est une base MySQL comme dit précédemment, se compose de 3 tables. De base, nous avions opté pour 2 tables : l'une pour stocker les utilisateurs de la plateforme et leur mot de passe relatif, l'autre pour stocker les capteurs et la mise à jour des données.
	\par
	Ce modèle était valide pour nos tests de début de projet mais s'est montré très limité quand nous avons décidé d'analyser les données des capteurs et spécialement quand nous avons décidé de stocker dans la durée les données. Par exemple, nous avions besoin de plusieurs données d'un même capteur pour dessiner un graphe ou plus simplement comparer différentes mesures.
	Comme nous stockions uniquement la dernière mesure (les informations étaient écrasées à chaque mise à jour), nous ne pouvions stocker plusieurs mesures d'un même capteur. Nous avons donc changé notre implémentation des tables dans la base.
	\par
	Nous aurions pu garder seulement 2 tables, en insérant simplement les nouvelles données dans la table des capteurs au lieu de mettre à jour les champs correspondant. Cette idée n'a pas pu être mise en place car cette table possède un champ 'ID' qui est la clé primaire de la table. Or il aurait fallu avoir plusieurs entrées comportant le même 'ID', ce qui est impossible.
	\par
	C'est donc à ce moment là que la table des capteurs est devenue la table répertoriant la liste des capteurs et une nouvelle table stockant toutes les données des capteurs a été crée.
	\par
	Les relations entre ces différentes tables sont schématisées sur la figure suivante et détaillées ci dessous:
	 \begin{figure}[h]
  		\centering
    		
		\caption {diagramme des tables}
	\end{figure}
	\par
	La table 'users' répertorie les différents utilisateurs de la plateforme Web. C'est à travers elle qu'un utilisateur est autorisé à se connecter, sous réserve que son nom et son mot de passe sont corrects.
	\par
	La table 'data' est la table répertoriant les différents capteurs. C'est à travers elle qu'un capteur est autorisé à mettre à jour ses données. Elle stocke aussi la date de dernière mise à jour du de chaque capteur.
	\par
	La table 'captors' est la table stockant les données de chaque capteur. C'est en quelque sorte l'extension de la table 'data'. Chaque champ, défini par son 'ID' ou son 'Name' est relié à une entrée de la table 'data' et complète cette dernière.
	\subsection{La plateforme}
	\par
	Le site se découpe en 4 modules (3 pour un utilisateur lambda) dont un visuel se situe en annexe.
	Pour construire ce site, nous avons utilisé différents langages et outils qui seront développés ci dessous.
	\subsubsection{Les différents modules}
	\par
	Le site Web contient 4 modules différents qui ont chacun une fonction particulière. Le premier est celui qui apparait en premier sur le site. Il autorise la connection à la plateforme. Une fois l'utilisateur connecté, il affiche les 5 dernières mises à jour des capteurs.
	\par
	Le deuxième module permet la recherche d'informations sur un capteur. La recherche s'effectue soit par 'ID' soit par 'Nom'. Une fois le capteur choisi, toutes les données disponibles le concernant s'affiche ansi que deux graphiques des 10 dernières mesures (un pour la température et un pour la luminosité).
	\par
	Le troisième module regroupe l'ajout et la suppression des capteurs. Il est nécessaire de déclarer et autoriser les capteurs en vue de leur mise à jour car si les capteurs ne sont pas répertoriés dans la base, leurs informations ne seront pas prise en compte (permet de sécuriser la mise à jour d'informations au cas où un tierce voudrait compromettre la base de données). Si le capteur n'est plus utilisé, on le supprime de la base à travers cette interface.
	\par
	Le dernier module n'est accessible qu'à l'administrateur de la plateforme. Il regroupe les fonctions d'administration : il permet l'ajout ou la suppression d'un utilisateur, la suppression complète des données des capteurs (en vue d'une remise à zéro) et un panneau de supervision. Ce dernier permet de repérer quels capteurs n'ont pas effectué leur mise à jour (en prenant comme référence la dernière heure). 
	\subsubsection{Le design : Ink}
	\par
	Pour cette plateforme, nous avons voulu faire quelque chose de visuellement propre. C'est donc dans cette optique que nous avons décidé d'utiliser un framework css. Ink est le framework libre qui s'occupe du design de notre site. Il nous a permis de donner un style simple à notre site, une fois maitrisé.
	\par
	La principale difficulté a été de comprendre comment fonctionnait Ink. En effet, en dehors des classes qui lui sont propres, il utilise un système de grille. Chaque morceau du site est découpé et se positionne sur la grille. Ce système structure le site et offre une interface épuré avec de nombreuses possibilité déjà implanté.
	\par
	L'utilisation de Ink se justifie par la qualité visuelle que l'on n'aurait pas pu atteindre par nous même, par manque de temps et certainement de talent graphique.
	\subsubsection{La gestion des données : PHP et Requêtes}
	\par
	L'interaction entre l'utilisateur et le base de données est assurée par PHP. C'est lui qui s'occupe de récupérer, mettre à jour et supprimer les informations demandées ou envoyées par l'utilisateur et le capteur. Il permet aussi d'executer du code en fonction de différents paramètres. C'est lui qui va être le moteur de l'application.
	\par
	Dans un premier temps, il permet d'executer et d'afficher sur la page ce qui est demandé par l'utilisateur, par exemple si l'utilisateur n'a pas encore demandé d'informations sur un capteur, on lui propose de faire un choix entre différents capteurs. Une fois qu'il en a sélectionné un (c'est à dire après l'envoi en POST du choix), PHP récupère cette information et prépare la page pour répondre à la demande de l'utilisateur. Pour illustrer cette fonction, on prend pour exemple le code suivant :
	\\%
	\lstset{language=PHP} 
	\begin{lstlisting}[frame=single]
/*Si on a recu une information d'ID, c'est a dire que l'utilisateur
demande une info sur une ID*/		
if(isset($_POST['id'])){
	//On execute les actions appropriees
}
	\end{lstlisting}
	\par
	La deuxième utilité de PHP est de pouvoir interagir directement avec la BDD. En utilisant PDO, on va se connecter à la base et executer des requêtes qu'on récupérera avec PHP.
	PDO est une méthode orientée objet d'interaction avec différents types de BDD (Mysql, PosgreSQL, etc...) qui est destiné à être la méthode principale à utiliser dans les prochaines versions de PHP. Le choix de PDO se justifie par sa capacité à préparer les requêtes avant de les executer  (on execute les requêtes en fonction de paramètres et non plus statiquement) et par l'importance qu'il prendra dans les versions futures de PHP (il est voué à être la méthode principale de connection, ce qui assure que l'application fonctionnera avec les versions futures).
	\par
	PDO fonctionne de la manière suivante :
	\\%
	\lstset{language=PHP} 
	\begin{lstlisting}[frame=single]
/*On instancie une variable PDO en PHP contenant
toutes les informations de connexion a la base de donnees*/
$bdd = new PDO('mysql:host=hostofthedatabase;dbname=nameofthedb', 
'user', 'password');
/*On prepare la requete avec en option un parametre
represente par "?"*/
$check=$bdd->prepare("SELECT login, password FROM users WHERE
login=?");
/*On execute la requete avec comme parametre "Jesuisunutilisateur"*/
$check->execute(array(Jesuisunutilisateur));
/*On recupere le resultat de la requete dans une variable pour une
utilisation ulterieure*/
$data=$check->fetch();
/*Une fois fini, on ferme proprement la connection a la base de 
donnees*/
$check->closeCursor();
	\end{lstlisting}
		
	\par
	Afin de gérer correctement les échanges d'informations entre le site et la base de données, quatre opérations différentes sont utilisées par PHP/PDO en utilisant le format MySQL :
	\\%
	\begin{itemize}
	\item Insérer des données dans la BDD : 
	\lstset{language=SQL} 
	\begin{lstlisting}[frame=single]
 Ex: INSERT INTO captors(temp,lum,timestamp,id) VALUES(?,?,?,?)
	\end{lstlisting}
	\item Obtenir des données de la BDD : 
	\lstset{language=SQL} 
	\begin{lstlisting}[frame=single]
Ex : SELECT login, password FROM users
	\end{lstlisting}
	\item Mettre à jour des données dans la BDD : 
	\lstset{language=SQL} 
	\begin{lstlisting}[frame=single]
Ex : UPDATE data SET timestamp=? WHERE id=?
	\end{lstlisting}
	\item Supprimer des données dans la BDD : 
	\begin{lstlisting}[frame=single]
Ex : DELETE  captors FROM captors WHERE timestamp  <  ?
	\end{lstlisting}
	\end{itemize}
	\subsubsection{Recup.php}
	\par
	La plus grosse partie du site consiste à faire interagir l'utilisateur avec la base de données. Cependant, il existe une page de site (recup.php) qui n'interagit pas avec l'utilisateur mais avec les capteurs. Celle ci reçoit des informations des capteurs (via POST), vérifie si le capteur a le droit de mettre à jour les données et effectue l'insertion dans la base.
	\par
	Cette page n'a pas seulement l'utilité de mise à jour, elle s'occupe aussi de la conversion des données de température. On s'est aperçu que les mesures brutes des capteurs venant de l'adc devait être multipliées par un coefficient (0,647) pour obtenir une valeur cohérente en température. Cette multiplication n'étant pas faite par l'Arduino (pour le soulager un peu), on a choisi  de donner cette tâche à PHP.
	\par
	En dernier lieu, cette page se charge de nettoyer la table de données des capteurs en supprimer toute entrée datant de la veille via la fonction \href{http://www.php.net/manual/fr/function.date.php}{Date de PHP.}
	\subsubsection{Du dynamisme : Javascript} 
	\par
	Le Javascript sur le site est utilisé pour donner dynamiser l'utilisation du site. Il nous a permis de rediriger automatiquement l'utilisateur et principalement de gérer l'ajout de champ dans les pages d'ajout et de suppression de capteurs.
	En effet, nous l'avons utilisé pour permettre d'effectuer plusieurs actions identiques en une seule fois.
	\par
	Par exemple, quand on veut ajouter en chaine plusieurs capteurs, on aurait pu les ajouter un par mais cela aurait alourdi grandement l'application. La solution est simple, à chaque clic sur un bouton (dans notre cas, un "+"), le javascript insère un nouveau champ sur la page. 
	Cela se traduit par le code suivant : 
	\\%
	\lstset{language=Java} 
	\begin{lstlisting}[frame=single]
// On recupere le cadre ou on va inserer le nouvel element
var div = document.getElementById('champs');

// Fonction qui va creer l'element
function addInput(name,placeholder){
	var input = document.createElement("input");
	input.name = name;
	input.placeholder = placeholder; 
	div.appendChild(input);
}

// On ajoute l'element a la page
	function addField() {
	div.appendChild(document.createElement("br"));
	addInput("name[]","Nom du capteur");
	addInput("password[]","Mot de passe du capteur");
}	
	\end{lstlisting}
	\subsection{Des idées d'amélioration}
	\par
	Plusieurs améliorations peuvent être apportées à la plateforme Web, certaines avaient déjà été pensées au début du projet mais non implantées.
	\par
	En premier lieu, le pattern MVC aurait du être celui de base mais par manque de temps et surtout par sa complexité (principalement avec l'utilisation parallèle d'Ink), il n'a pas été utilisé.
	\par
	Par ailleurs, le site utilise le Javascript mais pourrait l'utiliser plus comme par exemple en rafraichissant la page de recherche d'informations pour permettre d'afficher les dernières informations et le graphique sans devoir recharger manuellement la page.
	\par
	En dernier lieu, on pourrait adapter les différents champs de la base (luminosité, température, etc) ainsi que le code selon les besoins réels (capteur de luminosité, température, pression, etc). On pourrait aussi optimiser le nombre de mesures des graphiques mais cela relève plus de l'optimisation que de l'amélioration.

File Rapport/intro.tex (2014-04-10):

\addcontentsline{toc}{section}{Introduction}
	\section*{Introduction}
		Les projets de quatrième année d'IMA sont l'occasion pour les étudiants
		de mener à bien un projet sur un relativement long terme en partenariat
		avec des industriels ou des laboratoires de recherche. Ils nous permettent
		de mettre en application des connaissances acquises pendant l'année
		et de les perfectionner autour d'un sujet complet, de l'élaboration
		du cahier des charges à une éventuelle réalisation finale.
		\par
		Nous avons donc pu nous pencher sur un problème concret pendant trois
		mois. Le sujet consistait en la réalisation d'un réseau de capteurs
		en wifi pour surveiller de grandes structures et de faire remonter
		des informations d'environnement telles que la température d'une salle,
		son éclairement ou l'éventuelle ouverture ou fermeture d'une porte.
		\par
		De telles données peuvent éventuellement être traitées en amont dans une
		logique d'économie d'énergie, ou tout simplement de surveillance de
		l'état d'un bâtiment.

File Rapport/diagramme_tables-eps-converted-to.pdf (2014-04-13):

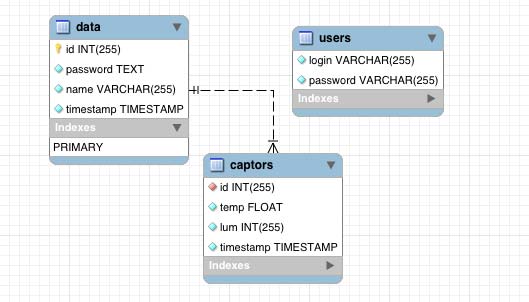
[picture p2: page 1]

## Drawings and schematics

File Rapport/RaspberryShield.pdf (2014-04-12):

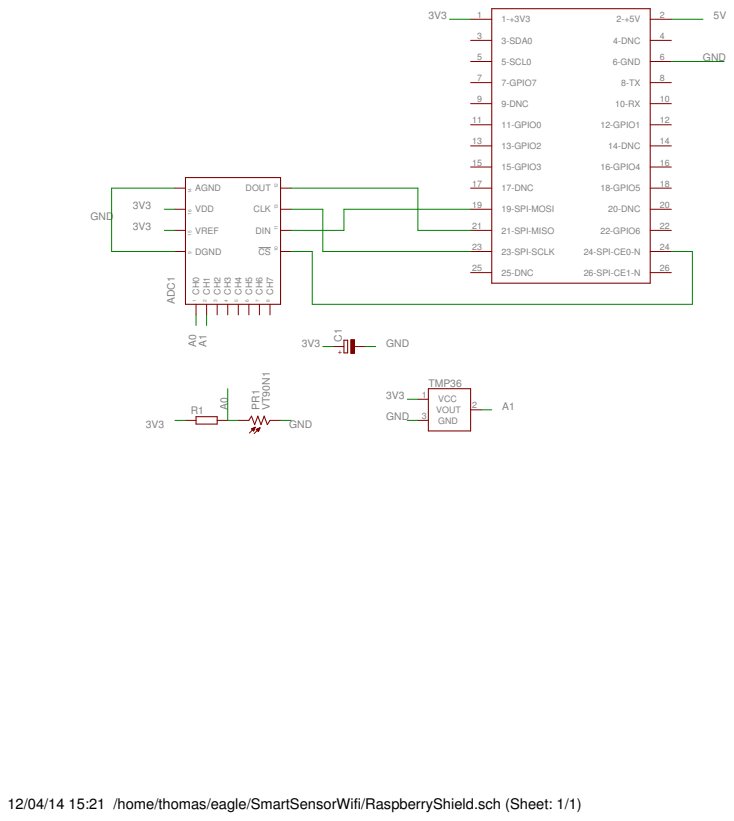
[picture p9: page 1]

12/04/14 15:21 /home/thomas/eagle/SmartSensorWifi/RaspberryShield.sch (Sheet: 1/1)

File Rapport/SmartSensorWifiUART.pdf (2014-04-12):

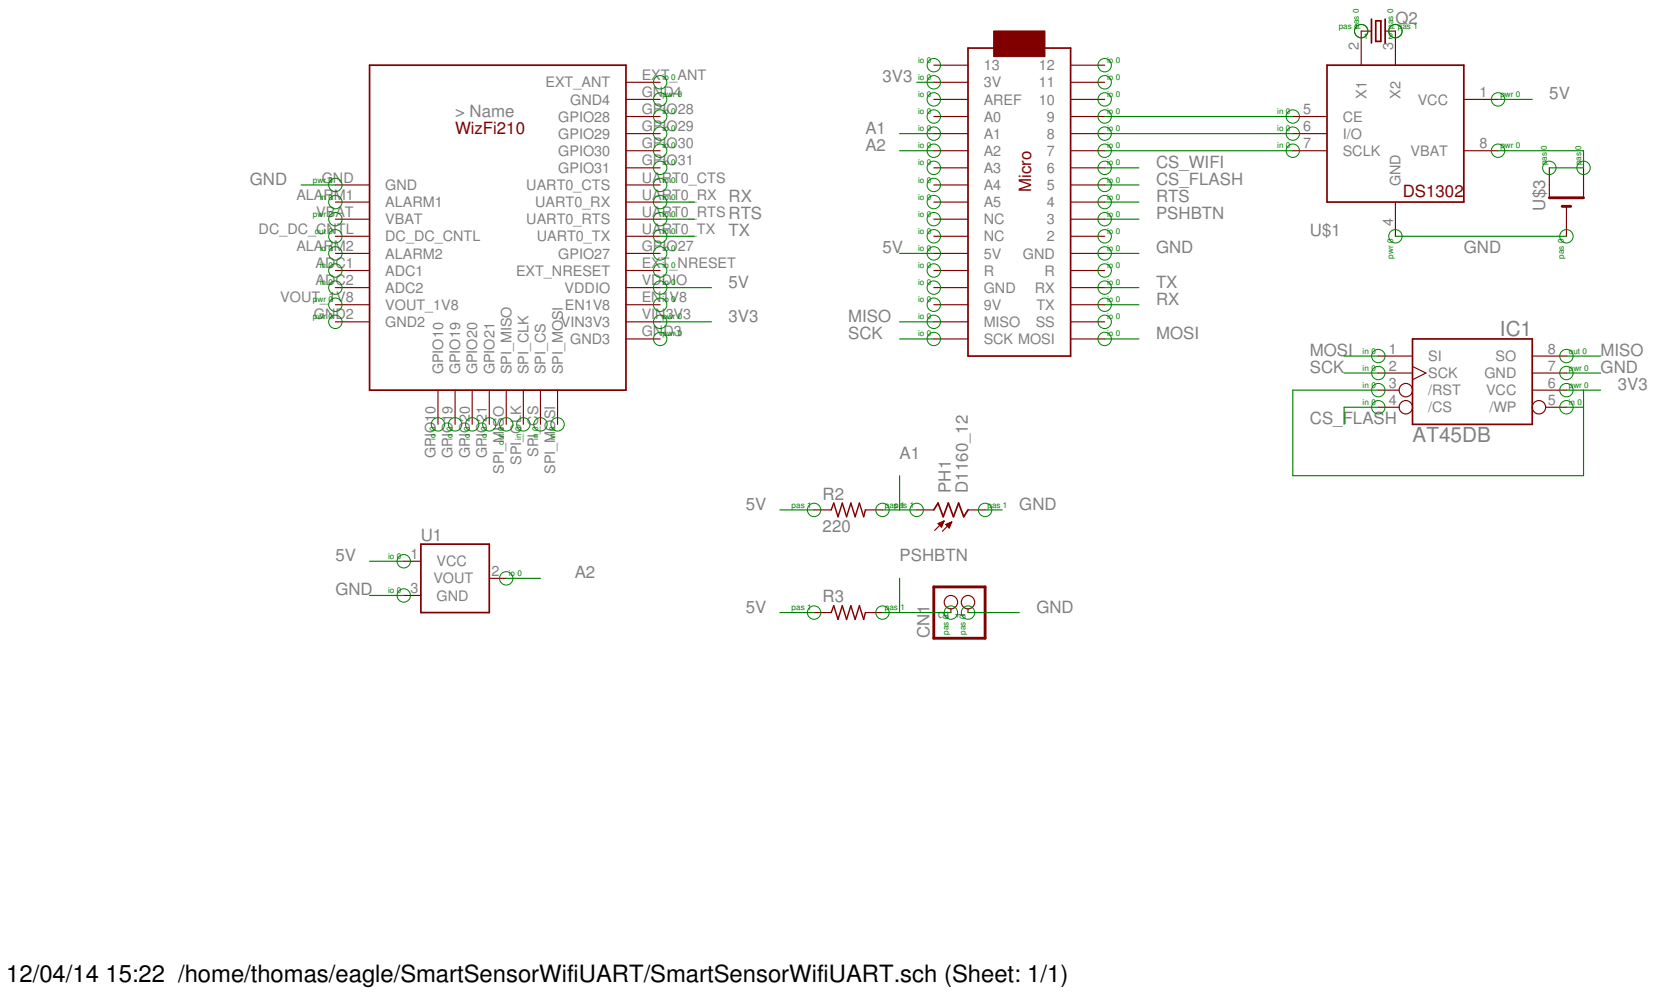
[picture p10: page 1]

12/04/14 15:22 /home/thomas/eagle/SmartSensorWifiUART/SmartSensorWifiUART.sch (Sheet: 1/1)

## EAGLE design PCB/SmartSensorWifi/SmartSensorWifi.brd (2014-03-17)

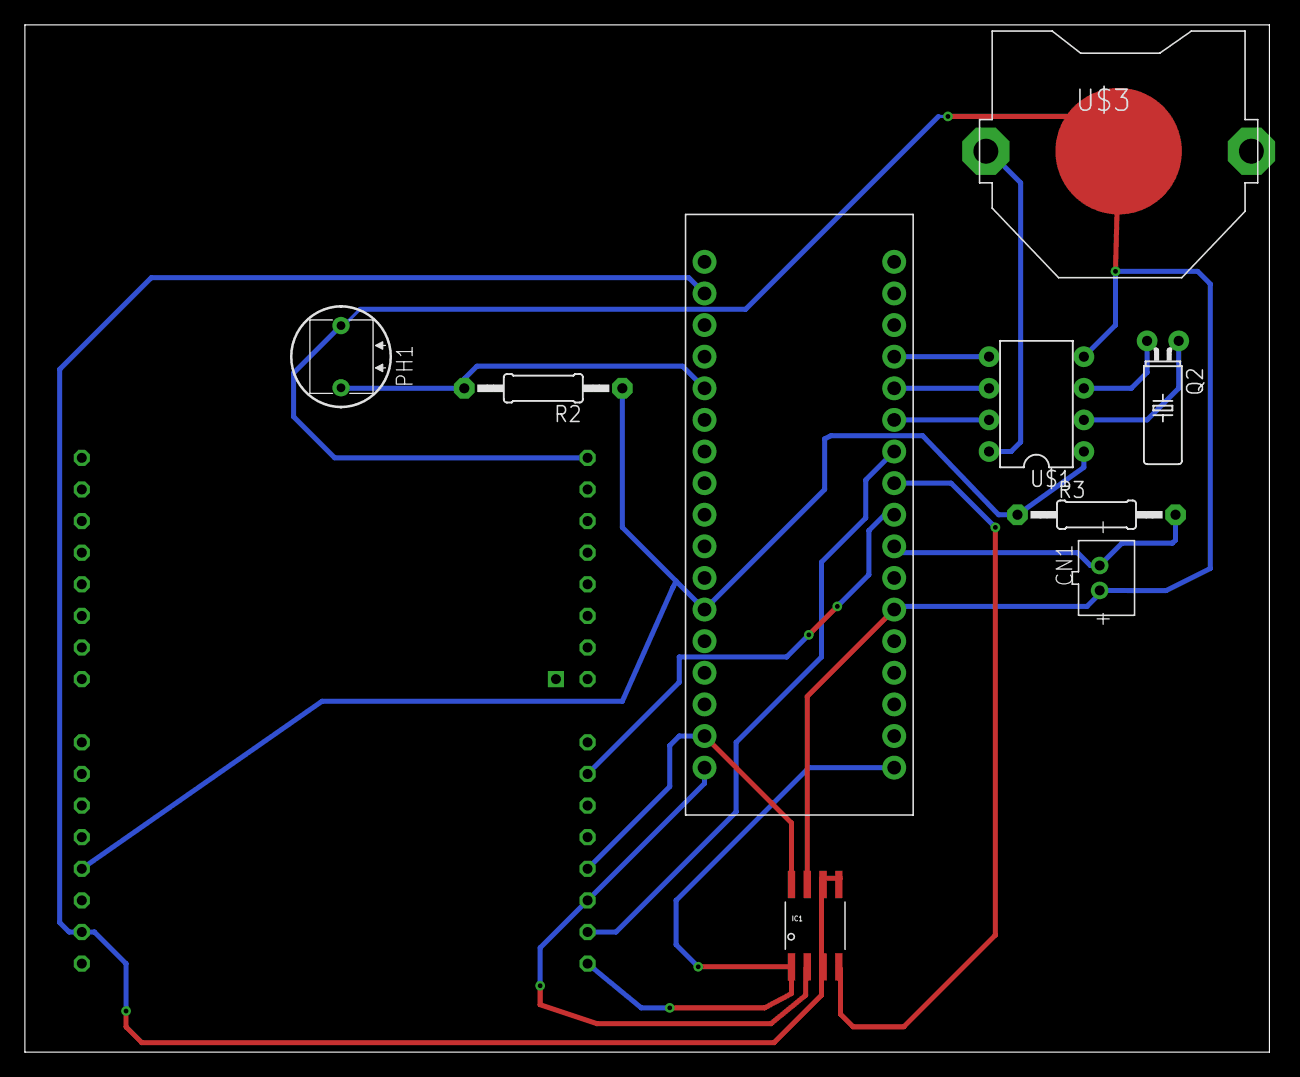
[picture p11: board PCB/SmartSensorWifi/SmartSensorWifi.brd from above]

Board: 2 copper layers, 100.0 x 82.5 mm, 10 parts (1 on the bottom side), 18 nets.

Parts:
CN1: JST-PH-2-THM
IC1: AT45DB-S; SOIC8_208MIL
PH1: D1160_12; D11XX
Q2: TC38H
R2: 220; 0207/12
R3: 0207/12
U$1: DS1302; DIL08-ROUND
U$2: ARDUINOMICRO
U$3: CR2032-THRU
U$4: WIZFISTACKED; WIZFI210STACKABLE

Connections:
3V3: IC1.3, U$2.P$33, U$4.VIN3V3
5V: R2.1, R3.1, U$1.1, U$2.P$23, U$4.VDDIO
A1: PH1.1, R2.2, U$2.P$30
CS_FLASH: IC1.4, U$2.P$8
CS_WIFI: U$2.P$7, U$4.SPI_CS
GND: CN1.1, IC1.7, U$1.4, U$2.P$21, U$3.-
MISO: IC1.8, U$2.P$19, U$4.SPI_MISO
MOSI: IC1.1, U$2.P$17, U$4.SPI_MOSI
unnamed: U$1.5, U$2.P$4
unnamed: Q2.2, U$1.3
unnamed: Q2.1, U$1.2
unnamed: U$1.7, U$2.P$6
unnamed: U$1.6, U$2.P$5
unnamed: U$1.8, U$3.+1
PSHBTN: CN1.2, R3.2, U$2.P$10
S$1: PH1.2, U$4.GND
SCK: IC1.2, U$2.P$18, U$4.SPI_CLK
WIFI_HOSTWAKEUP: U$2.P$9, U$4.GPIO19

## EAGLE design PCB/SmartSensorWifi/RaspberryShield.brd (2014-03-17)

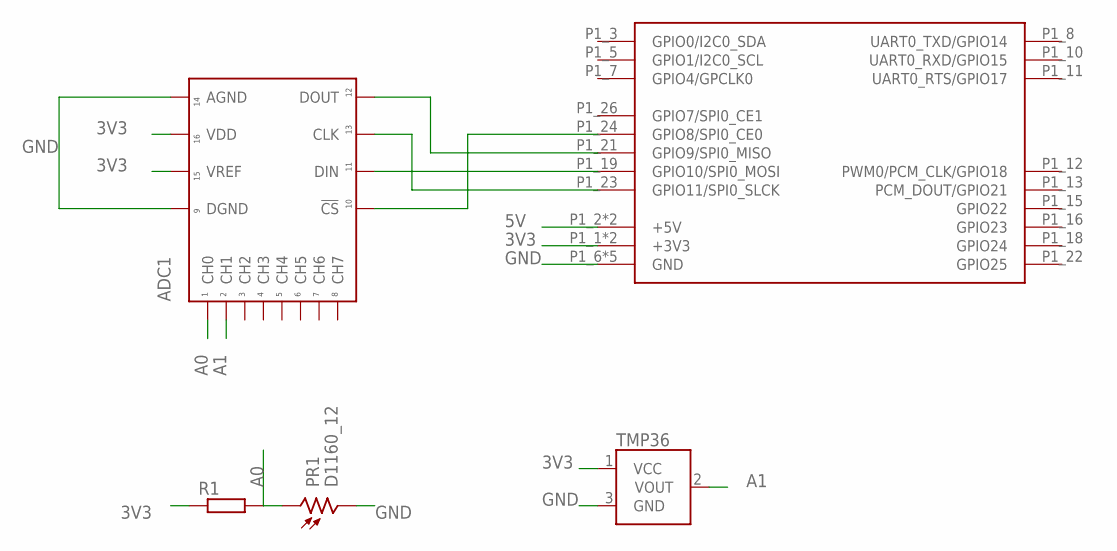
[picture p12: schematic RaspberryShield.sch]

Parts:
ADC1: 21298EDIP; DIP16
PR1: D1160_12; D11XX
R1: R-EU_0207/7; 0207/7
TMP36: TMP36GT9; TO-92
U$1: RPI-B-V1SHIELD; RPI-B-V1-SHIELD

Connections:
3V3: ADC1.P$15 (VREF), ADC1.P$16 (VDD), R1.1, TMP36.1 (VCC), U$1.P1_1 (+3V3), U$1.P1_17 (+3V3)
5V: U$1.P1_2 (+5V), U$1.P1_4 (+5V)
A0: ADC1.P$1 (CH0), PR1.1, R1.2
A1: ADC1.P$2 (CH1), TMP36.2 (VOUT)
GND: ADC1.P$9 (DGND), ADC1.P$14 (AGND), PR1.2, TMP36.3 (GND), U$1.P1_6 (GND), U$1.P1_9 (GND), U$1.P1_14 (GND), U$1.P1_20 (GND), U$1.P1_25 (GND)
unnamed: ADC1.P$12 (DOUT), U$1.P1_21 (GPIO9/SPI0_MISO)
unnamed: ADC1.P$11 (DIN), U$1.P1_19 (GPIO10/SPI0_MOSI)
unnamed: ADC1.P$13 (CLK), U$1.P1_23 (GPIO11/SPI0_SLCK)
unnamed: ADC1.P$10 (!CS), U$1.P1_24 (GPIO8/SPI0_CE0)

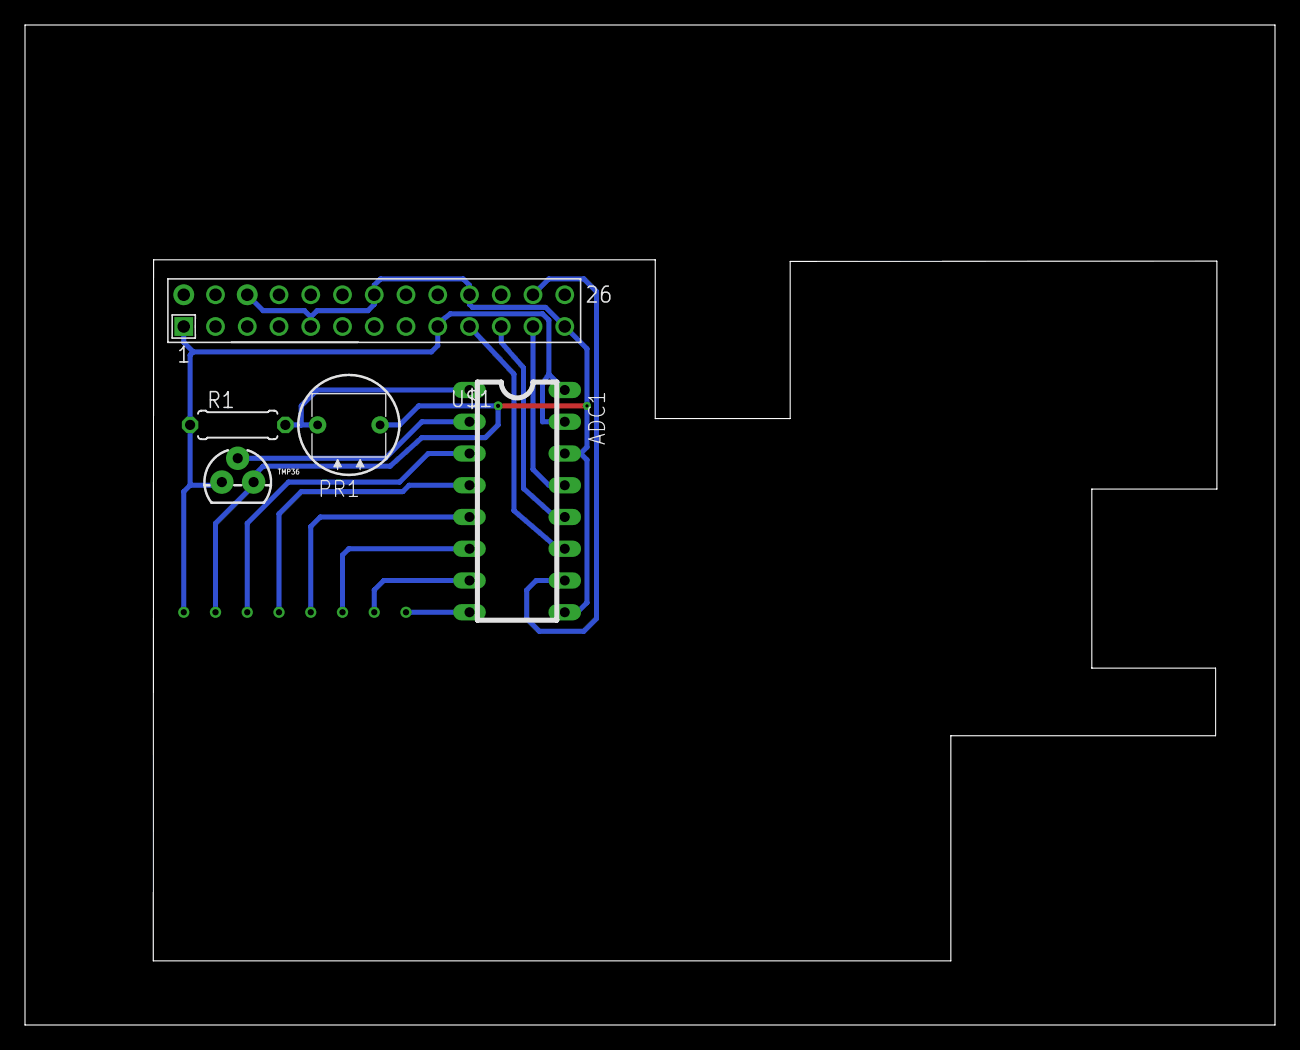
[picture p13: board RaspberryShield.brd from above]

Board: 2 copper layers, 100.0 x 80.0 mm, 5 parts (0 on the bottom side), 9 nets.

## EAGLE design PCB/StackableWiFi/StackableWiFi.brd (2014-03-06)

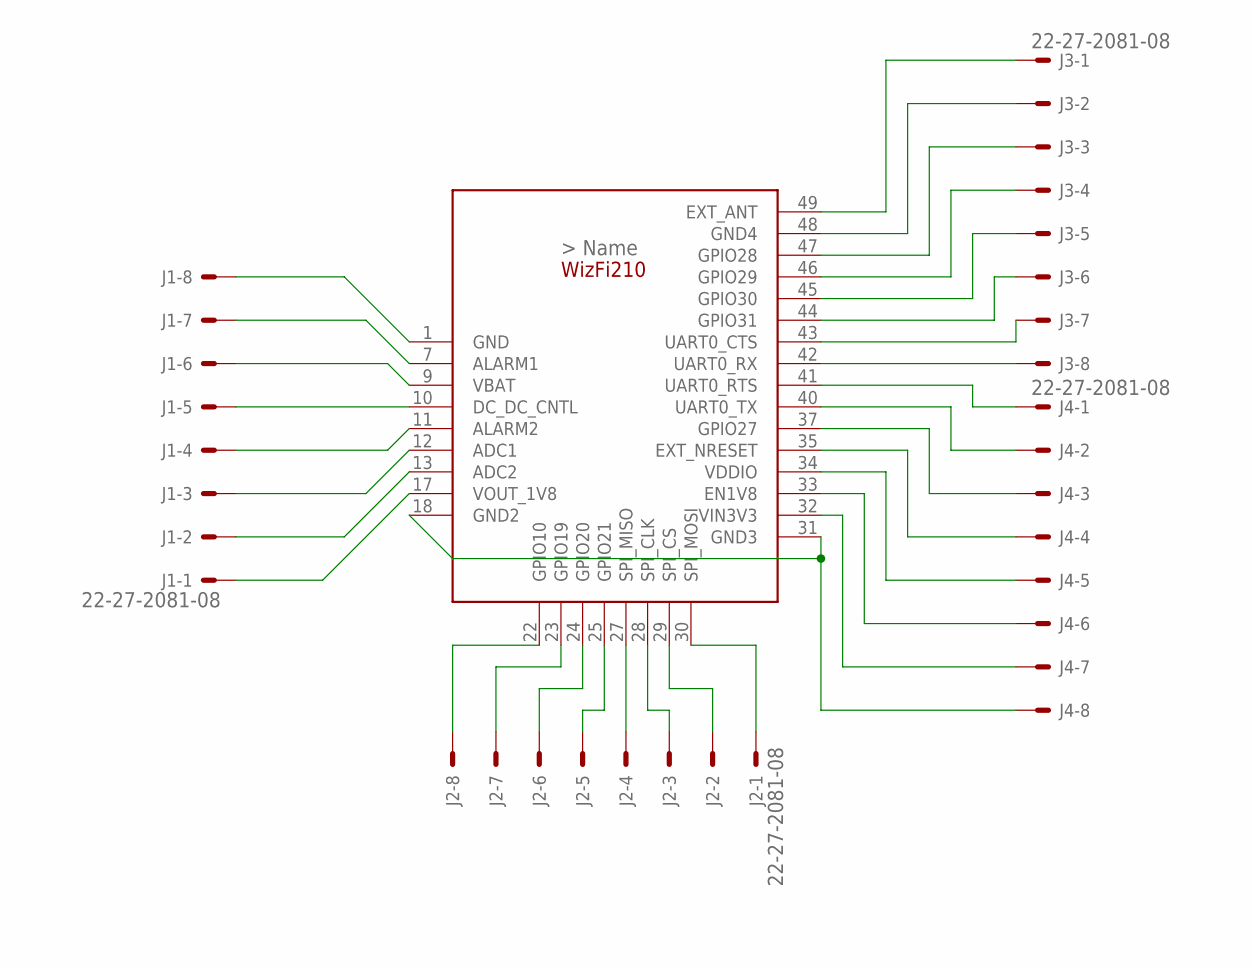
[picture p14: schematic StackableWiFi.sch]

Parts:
J1, J2, J3, J4: 22-27-2081-08; 6410-08
WIFI1: WIZFI210

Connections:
unnamed: J1.8, WIFI1.1 (GND)
unnamed: J1.7, WIFI1.7 (ALARM1)
unnamed: J1.6, WIFI1.9 (VBAT)
unnamed: J1.5, WIFI1.10 (DC_DC_CNTL)
unnamed: J1.4, WIFI1.11 (ALARM2)
unnamed: J1.3, WIFI1.12 (ADC1)
unnamed: J1.2, WIFI1.13 (ADC2)
unnamed: J1.1, WIFI1.17 (VOUT_1V8)
unnamed: J4.8, WIFI1.18 (GND2), WIFI1.31 (GND3)
unnamed: J2.8, WIFI1.22 (GPIO10)
unnamed: J2.7, WIFI1.23 (GPIO19)
unnamed: J2.6, WIFI1.24 (GPIO20)
unnamed: J2.5, WIFI1.25 (GPIO21)
unnamed: J2.4, WIFI1.27 (SPI_MISO)
unnamed: J2.3, WIFI1.28 (SPI_CLK)
unnamed: J2.2, WIFI1.29 (SPI_CS)
unnamed: J2.1, WIFI1.30 (SPI_MOSI)
unnamed: J4.7, WIFI1.32 (VIN3V3)
unnamed: J4.6, WIFI1.33 (EN1V8)
unnamed: J4.5, WIFI1.34 (VDDIO)
unnamed: J4.4, WIFI1.35 (EXT_NRESET)
unnamed: J4.3, WIFI1.37 (GPIO27)
unnamed: J4.2, WIFI1.40 (UART0_TX)
unnamed: J4.1, WIFI1.41 (UART0_RTS)
unnamed: J3.8, WIFI1.42 (UART0_RX)
unnamed: J3.7, WIFI1.43 (UART0_CTS)
unnamed: J3.6, WIFI1.44 (GPIO31)
unnamed: J3.5, WIFI1.45 (GPIO30)
unnamed: J3.4, WIFI1.46 (GPIO29)
unnamed: J3.3, WIFI1.47 (GPIO28)
unnamed: J3.2, WIFI1.48 (GND4)
unnamed: J3.1, WIFI1.49 (EXT_ANT)

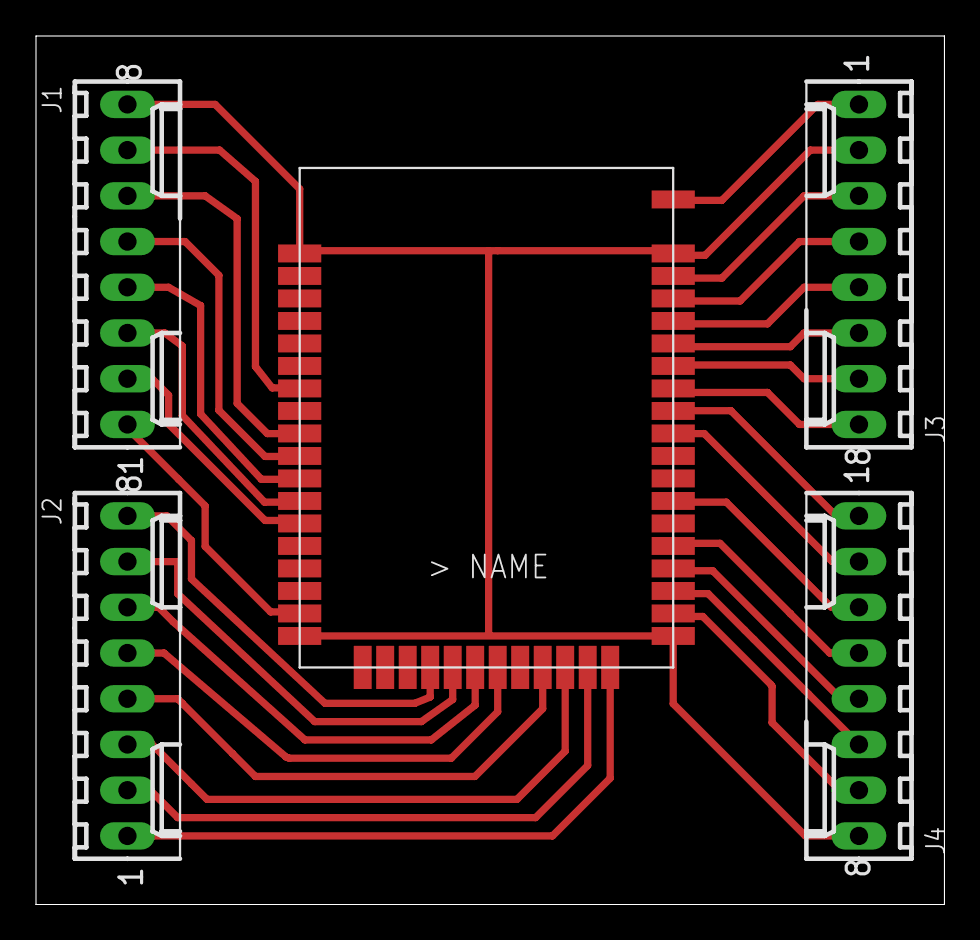
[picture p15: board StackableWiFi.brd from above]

Board: 2 copper layers, 50.5 x 48.2 mm, 5 parts (0 on the bottom side), 32 nets.

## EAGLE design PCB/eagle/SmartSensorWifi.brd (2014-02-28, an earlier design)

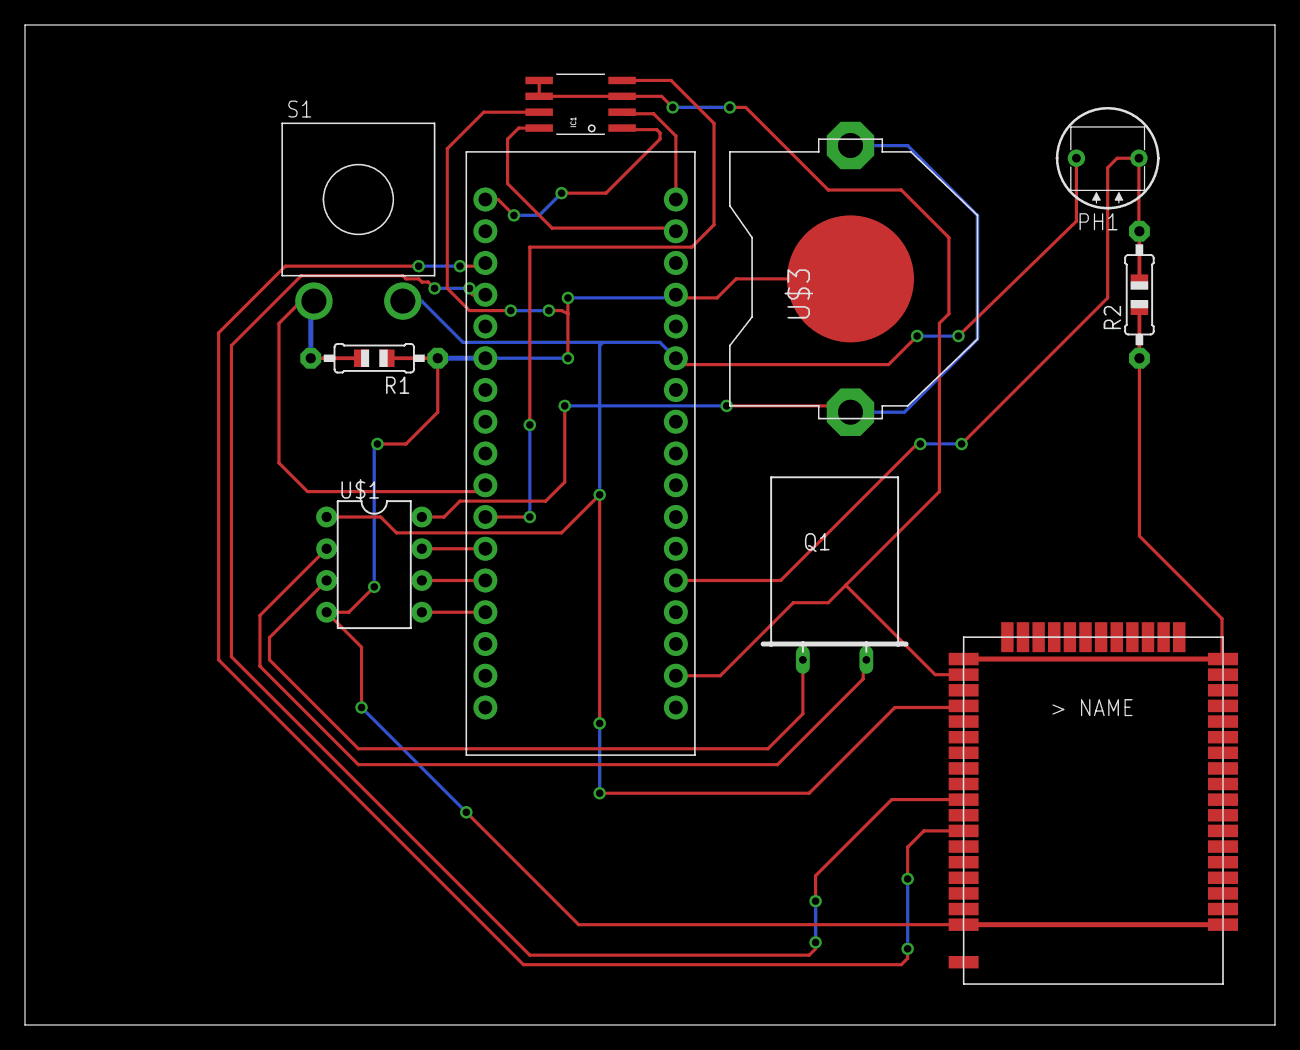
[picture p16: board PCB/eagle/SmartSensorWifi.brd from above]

Board: 2 copper layers, 100.0 x 80.0 mm, 10 parts (0 on the bottom side), 17 nets.

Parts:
IC1: AT45DB-S; SOIC8_208MIL
PH1: D1160_12; D11XX
Q1: Q
R1, R2: 0805-THM
S1: SPST; JUDCOSPST
U$1: DS1302; DIL08-ROUND
U$2: ARDUINOMICRO
U$3: CR2032-THRU
WIFI1: WIZFI210

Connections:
GND: IC1.7, R1.1, R2.1, U$1.4, U$2.P$12, U$2.P$21, U$3.-, WIFI1.1, WIFI1.18, WIFI1.31, WIFI1.48
unnamed: U$1.5, U$2.P$4
unnamed: Q1.1, U$1.3
unnamed: Q1.2, U$1.2
unnamed: U$1.7, U$2.P$6
unnamed: U$1.6, U$2.P$5
unnamed: IC1.8, U$2.P$19
unnamed: IC1.2, U$2.P$18
unnamed: IC1.1, U$2.P$17
unnamed: IC1.3, IC1.5, IC1.6, U$2.P$33, WIFI1.32
unnamed: U$1.8, U$3.+1, U$3.+2
unnamed: IC1.4, U$2.P$7
unnamed: R1.2, S1.T, U$2.P$8
unnamed: U$2.P$14, WIFI1.40
unnamed: U$2.P$15, WIFI1.42
unnamed: PH1.2, R2.2, U$2.P$30
VCC: PH1.1, S1.P, U$1.1, U$2.P$23, WIFI1.34

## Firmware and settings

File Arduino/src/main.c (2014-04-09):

/*
 *
 *	Copyright (C) 2014 Thomas MAURICE <tmaurice59@gmail.com>
 *
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
 *	You should have received a copy of the GNU General Public License along
 *	with this program; if not, write to the Free Software Foundation, Inc.,
 *	51 Franklin Street, Fifth Floor, Boston, MA 02110-1301 USA.
 */
 
/**
 * \file main.c
 * \author Thomas Maurice
 * 
 * \brief Main file of the Smart Sensor Wifi project
 * \version 0.1
 * 
 * This file demonstrates a simple HTTP serial server.
 * Optimized for an atmega8.
 */

/**
 * \mainpage Smart sensor WiFi
 * 
 * # Introduction
 * 
 * This project is a student project managed by Polytech Lille Engineering
 * School. It is led by two students, *Thomas Maurice* and *Benoit Maliar*. Both
 * students in 4th year.
 * 
 * The aim of the project is to create a distributed WiFi sensor network
 * that is able to regularly communicate various data to a central DB and
 * autoreconfigure itself in order to be energy efficient.
 * 
 * This part of the project is the microcontroller part of the project. The
 * main components used are an atmega328p, a DS1302 real time clock and a
 * WizFi210 WiFi chip.
 * 
 * Note that the project is open source and you can modify it. Especially
 * the drivers for the RTC and the WiFi chip, you are more than welcome to
 * study and improve them.
 * 
 * # Compiling
 * 
 * To compile the project you just need AVR-gcc installed. Just go in the
 * `Arduino` directory and run `make`. Everything will compile well. If
 * not, just undo your changes to my code !
 * 
 * It will create a nice .hex for upload. If your target is an Arduino board
 * then just type `make flash` to upload it using the built-in bootloader.
 * If it is just a bare-metal atmega328p then wire it up to your USBASP
 * device and run avrdude with the good options.
 * 
 * Have fun :)
 */

// CS de la carte wifi : PD6
// CS de la flash : PD5

#include <avr/io.h>
#include <avr/interrupt.h> 	
#include <avr/sfr_defs.h>
#include <util/delay.h>
#include <stdlib.h>
#include <string.h>

#include <adc.h>
#include <macros.h>
#include <serial.h>
#include <eep.h>
#include <ds1302.h>
#include <spi.h>
#include <wizFi210.h>
#include <timer.h>

// Json : '{"key":"value","key2":"value2"}'

/**
 * \brief Main function of the program
 * 
 * Will just perform the initializations of the chip, since
 * the whole thing is interrupt-driven.
 */
int main(void)
{	
	// Peripherals inits
	serial_init();
	adc_init();
	init_spi();
	init_timer();
	
	cbi(DDRD, PD2);
	sbi(DDRB, PB2); // For status led
	
	_delay_ms(500);
	if(gbi(PIND, PD2)==0) {
		int id=1;
		while(wizFi210_get_next_command('0', &id)==0);
	}
	
	//while(wizFi210_get_next_command('0')==0);
	/*uint8_t l = eeprom_read_word(EEP_DHCP);
	
	serial_send(l);
	l = eeprom_read_word(EEP_DHCP+1);
	
	serial_send(l);
	
	while(1);*/
	
	// Register inits
	sbi(DDRB,PB5); // To blink the LED L
	
	/*while(1) {
		_delay_ms(1000);
		adc_print_conv(1);
	}*/
	
	sei(); // Global interruption enable
	
	// Let's enable the clock !
	ds1302_clear_write_protect();
	ds1302_clear_clock_halt();
	
	ds1302_set_date(5, 3, 2014);
	
	/*display_clear();
	cli();
	serial_send_string_nt("\rAT+WM=0\r");
	if(wizFi210_check_ok() == 0) {
		serial_send_string_nt("OKTAMERE\r");
		if(wizFi210_check_ok() == 1)
			serial_send_string_nt("ERR\r");
		sei();
	}*/
	
	/*serial_send_string_nt("AT+NDHCP=0\r");
	serial_send_string_nt("AT+WSEC=8\r");
	serial_send_string_nt("AT+WPAPSK=net,pass\r");
	serial_send_string_nt("AT+WA=net\r");
	*/
	wizFi210_login_to_network();
	
	//serial_send_string_nt("AT+NSET=172.26.240.13,255.255.255.0,172.26.240.254\r");
	
	//_delay_ms(1000);
	//serial_send_string_nt("AT+PING=172.26.240.254,1\r");
	//_delay_ms(1000);
	//serial_send_string_nt("AT+WS\r");
	//serial_send_string_nt("AT+NCTCP=193.48.57.56,80\r");

	//wizFi210_send_update();
	
	serial_send_string_nt("AT+NSTCP=80\r");
	
	for(;;){
		char cid = wizFi210_check_connect();

		int res = 0;
		int id = 0;
		
		while(wizFi210_get_next_command(cid, &id) == 0) { res++;};
		
		serial_send_string_nt("AT+NCLOSE=");
		serial_send(cid);
		serial_send('\r');
	}

	return 0;
}

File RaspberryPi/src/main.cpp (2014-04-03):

#include <iostream>
#include <cstdlib>
#include <cstdio>

#include <SPI.hpp>
#include <SPI_MCP3208.hpp>

using namespace std;

int main(int argc, char ** argv) {
	SPI_MCP3208 port = SPI_MCP3208("/dev/spidev0.0", 500000, SPI_MODE_0, 8);
	port.open_port();
	uint16_t val = port.readValue(true, 0);
	std::cout <<  "Valeur dec " << val << std::endl;
	port.close_port();
	return EXIT_SUCCESS;
}

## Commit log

2014-02-03 Ajout des propositions de technologies
2014-02-06 Added the Arduino part of the project
2014-02-06 Fixed upload speed to make it work on arduino nano
2014-02-08 Fixed crash in ASCII mode if non utf8 chars
    [pyserialcom.py]
2014-02-18 Added the DS1302 driver
2014-02-28 Added PCB folder
    [SmartSensorWifi.brd, SmartSensorWifi.sch]
2014-02-28 Updated board
    [SmartSensorWifi.brd, SmartSensorWifi.sch]
2014-03-06 Updated the eagle files
    [RaspberryShield.brd, RaspberryShield.sch, SmartSensorWifi.brd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]
2014-03-13 Updated the PCB/BRD files
    [RaspberryShield.brd, RaspberryShield.sch, SmartSensorWifi.brd]
2014-03-15 Added the Raspberry SPI soft
2014-04-03 Added configurator and the ability to configure the sensor via serial
2014-04-04 Configurator now works wirelessly
2014-04-09 Fixed master key issue
    [configurator.py, main.c, wizFi210.c]
2014-04-10 Added accomplishment, sensor, software
2014-04-10 Added accomplishment, sensor, HARDWARE
2014-04-14 Enhanced RaspberrySpi

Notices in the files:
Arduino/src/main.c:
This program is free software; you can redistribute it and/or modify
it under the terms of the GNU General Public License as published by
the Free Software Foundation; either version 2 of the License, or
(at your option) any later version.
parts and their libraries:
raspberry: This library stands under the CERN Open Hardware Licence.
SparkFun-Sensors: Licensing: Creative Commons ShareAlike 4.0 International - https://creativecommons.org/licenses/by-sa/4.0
